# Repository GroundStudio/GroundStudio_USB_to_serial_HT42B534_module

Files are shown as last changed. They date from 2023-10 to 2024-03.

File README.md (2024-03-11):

GroundStudio USB to serial HT42B534 Module
====================================
USBTTL_Holtek REV0 2

Get it from [ardushop.ro](https://ardushop.ro/ro/home/1725-usbttlht42b534-2.html)

Explore all the GroundStudio products at [GroundStudio.ro](https://groundstudio.ro/)

Description
-------------------
USB to serial module based on HT42B534-2 chip.

Contents
-------------------

* [/Documentation](https://github.com/GroundStudio/GroundStudio_USB_to_serial_HT42B534_module/tree/main/Documentation) -- Contains documentation written during creation of this repository, with readme.md index of its own!
* [/Firmware](https://github.com/GroundStudio/GroundStudio_USB_to_serial_HT42B534_module/tree/main/Firmware) -- Firmware (bootloaders, etc)
* [/Hardware](https://github.com/GroundStudio/GroundStudio_USB_to_serial_HT42B534_module/tree/main/Hardware) -- Schematics, layout.
* [/Libraries](https://github.com/GroundStudio/GroundStudio_USB_to_serial_HT42B534_module/tree/main/Libraries) -- Arduino/CircuitPython libraries. 
* [/Tools](https://github.com/GroundStudio/GroundStudio_USB_to_serial_HT42B534_module/tree/main) -- Tools needed for compiling, uploading bootloader, etc.

Versions
-------------------
*(Not all tags shown)*
* [V0.2] Initial version

License
-------------------

This is released under the [Attribution-ShareAlike 4.0 International (CC BY-SA 4.0)](https://creativecommons.org/licenses/by-sa/4.0/) license. 
**You are welcome to use this for commercial purposes.**

Please consider contributing back to this project or others to help the open-source hardware community continue to thrive and grow! 

Certifications:

[Open Source Hardware Association](https://certification.oshwa.org/ro000011.html)   
   
certification-mark-RO000011-wide (https://certification.oshwa.org/ro000011.html)

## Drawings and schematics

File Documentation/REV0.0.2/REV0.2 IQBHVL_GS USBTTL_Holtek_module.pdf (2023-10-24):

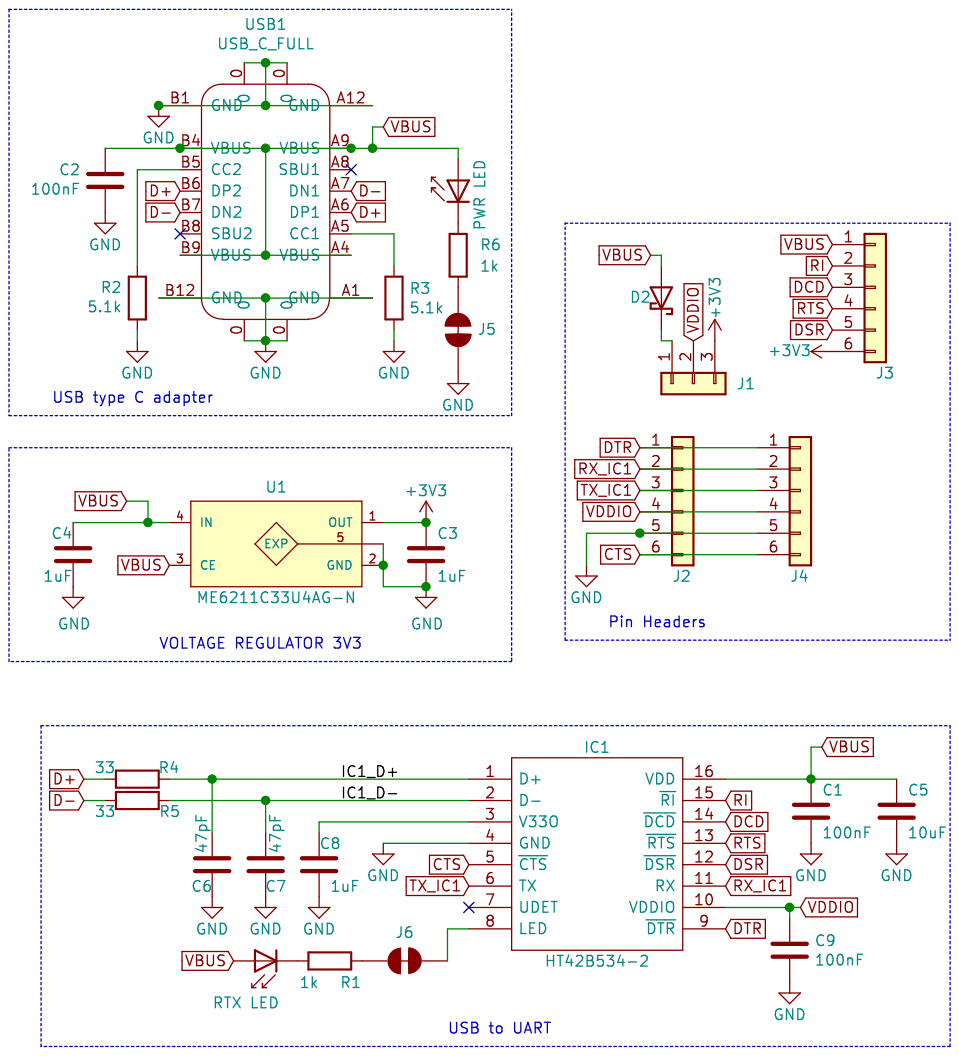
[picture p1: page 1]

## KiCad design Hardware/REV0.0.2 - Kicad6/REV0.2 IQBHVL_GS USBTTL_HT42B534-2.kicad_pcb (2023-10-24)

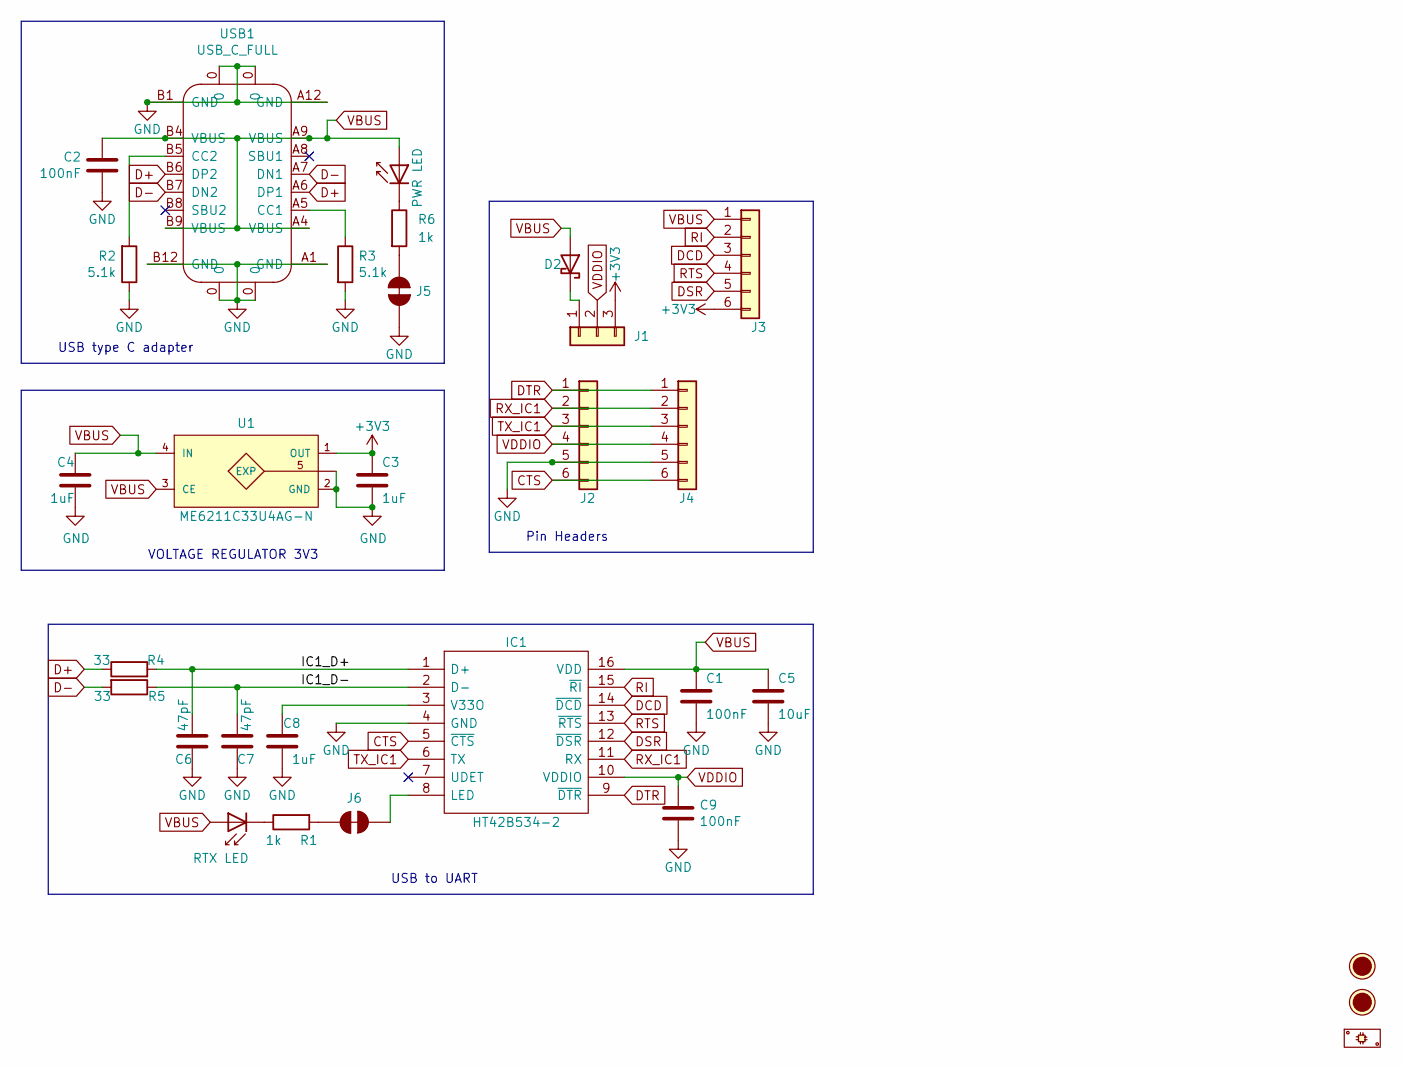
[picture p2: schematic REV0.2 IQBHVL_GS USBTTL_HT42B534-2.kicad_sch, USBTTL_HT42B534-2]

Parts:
C1, C2, C9: 100nF; C_0402_1005Metric; MPN 0402B104K100CT; LCSC C387941
C3, C4, C8: 1uF; C_0402_1005Metric; MPN FS15B105K100PKG; LCSC C525324
C5: 10uF; C_0402_1005Metric; MPN LDK105CBJ106MVLF; LCSC C386033
C6, C7: 47pF; C_0402_1005Metric; MPN FN15N470J500PNG; LCSC C525215
D1: RTX LED; LED_0402_1005Metric; MPN TZ-P2-0402GTIA1-0.45T; LCSC C688877
D2: D_Schottky; SOD-323; MPN SD103AWS; LCSC C438010
D3: PWR LED; LED_0402_1005Metric; MPN TZ-P2-0402RTIA1-0.45T; LCSC C779449
FID1, FID2: Fiducial; Fiducial_1mm_Mask2mm
IC1: HT42B534-2; SOP-16_150MIL; MPN HT42B534-2; LCSC C493361
J1: Conn_Male; PinHeader_1x03_P2.54mm_Vertical_Male; MPN C49257; LCSC C49257
J2: Conn_Female; PinHeader_1x06_P2.54mm_Vertical_Female; MPN C124415; LCSC C124415
J3, J4: Conn_Male; PinHeader_1x06_P2.54mm_Vertical_Male; MPN C37208; LCSC C37208
J5: PWR LED DISABLE; SolderJumper_NC
J6: SolderJumper_NC
P1: PCB; MPN IQBHVL_GS_PCB
R1, R6: 1k; R_0402_1005Metric; MPN RC-02W1001FT; LCSC C226166
R2, R3: 5.1k; R_0402_1005Metric; MPN RC-02W5101FT; LCSC C294638
R4, R5: 33; R_0402_1005Metric; MPN RC-02W33R0FT; LCSC C140161
U1: ME6211C33U4AG-N; FBP1-1-4; MPN ME6211C33U4AG-N; LCSC C428904
USB1: USB_C_FULL; USB_C_C167321; MPN 918-418K2023S40001; LCSC C167321

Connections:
+3V3: C3.1, J1.3, J3.6, U1.1 (OUT)
/IC1_D+: C6.1, IC1.1 (D+), R4.2
/IC1_D-: C7.1, IC1.2 (D-), R5.1
CTS: IC1.5 (~CTS), J2.6, J4.6
D+: R4.1, USB1.A6 (DP1), USB1.B6 (DP2)
D-: R5.2, USB1.A7 (DN1), USB1.B7 (DN2)
DCD: IC1.14 (~DCD), J3.3
DSR: IC1.12 (~DSR), J3.5
DTR: IC1.9 (~DTR), J2.1, J4.1
GND: C1.2, C2.1, C3.2, C4.2, C5.2, C6.2, C7.2, C8.2, C9.2, IC1.4 (GND), J2.5, J4.5, J5.1, R2.1, R3.2, U1.2 (GND), U1.5 (EXP), USB1.0, USB1.A1 (GND), USB1.A12 (GND), USB1.B1 (GND), USB1.B12 (GND)
unnamed: C8.1, IC1.3 (V33O)
unnamed: D1.1 (K), R1.1
unnamed: D2.1 (K), J1.1
unnamed: D3.1 (K), R6.1
unnamed: IC1.8 (LED), J6.1
unnamed: J5.2, R6.2
unnamed: J6.2, R1.2
unnamed: R2.2, USB1.B5 (CC2)
unnamed: R3.1, USB1.A5 (CC1)
RI: IC1.15 (~RI), J3.2
RTS: IC1.13 (~RTS), J3.4
RX_IC1: IC1.11 (RX), J2.2, J4.2
TX_IC1: IC1.6 (TX), J2.3, J4.3
VBUS: C1.1, C2.2, C4.1, C5.1, D1.2 (A), D2.2 (A), D3.2 (A), IC1.16 (VDD), J3.1, U1.3 (CE), U1.4 (IN), USB1.A4 (VBUS), USB1.A9 (VBUS), USB1.B4 (VBUS), USB1.B9 (VBUS)
VDDIO: C9.1, IC1.10 (VDDIO), J1.2, J2.4, J4.4

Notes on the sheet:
USB to UART
USB type C adapter
Pin Headers
VOLTAGE REGULATOR 3V3

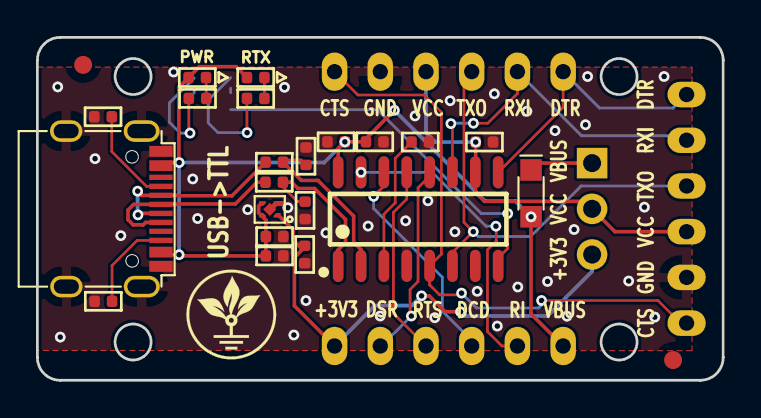
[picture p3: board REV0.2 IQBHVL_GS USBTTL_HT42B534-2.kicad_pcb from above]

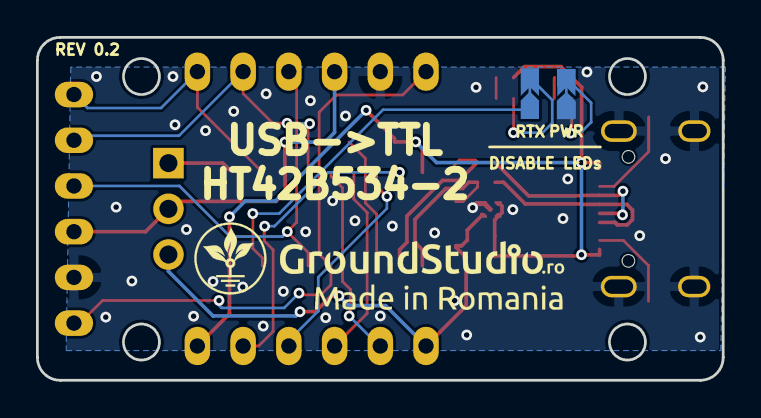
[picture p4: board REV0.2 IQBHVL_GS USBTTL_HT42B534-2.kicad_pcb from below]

Board: 2 copper layers, 38.1 x 19.1 mm, 29 parts (4 on the bottom side), 25 nets.

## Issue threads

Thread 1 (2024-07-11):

circuit does not allow for dual power mode

andrelabelle, 2024-07-11:
Hello,

This hardware can't be used in dual power mode as described in the HT42B534-x datasheet, see page 10 of Rev. 1.20 September 19, 2023. In this scenario, the target device has its own power supply so the circuitry needs to handle either side being power up and down independently.

There are different problems depending on the J1 jumper block setting.

1. jumper J1 pins 1,2 for VBUS as VCCIO or 2,3 for 3V3 as VCCIO: This doesn't work when the target device is powered down, the HT42B534 TX pin will idle in a high state, the target device will have a VBUS or 3V3 logic high level on its RX pin that is higher than its own VCC.

2. remove jumper from J1, target power is connected to VDDIO: This doesn't work when the USB cable is disconnected or the PC is powered down while the target device is powered up.  HT42B534 VDD will be 0V and the voltage applied to VDDIO will be higher than VDD. The datasheet says VDDIO MAX is VDD.
The circuit in the HT42B534 datasheet shows a diode from external VDDIO-3.3V to VBUS/VDD to handle this situation.
